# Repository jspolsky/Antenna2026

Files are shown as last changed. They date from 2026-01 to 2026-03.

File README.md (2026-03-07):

Future Turtles 2026 Public LED Display
====

In 2024 we
* upped the number of whips to 24
* got rid of the central antenna
* improved cabling via daisy chaining

For 2026 we
* made the box at the foot of each whip smaller
* hard wired those boxes instead of using external connectors
* used two sources of power so that 16awg wires are adequate
* implemented a bird game

2026 TODO LIST:
===============
- [x] Fix 50 foot cable issues (see below)
- [x] Test game rendering with actual whips
- [x] Replace 600W power supplies with 300W
    - [x] Test temperature inside power packs
    - [x] Install new mounting plates     
- [x] Provide a way to separate left and right halves of whip control harness
    - [x] Modify setup documentation accordingly
- [ ] Implement game button
    - [x] Revise controller PCB to expose more pins (sent to JLCPCB)
    - [x] Rebuild controllers
    - [x] Cable to game button
    - [ ] Game button mounting hardware 
- [x] Finalize game code and flash it onto every MCU
- [ ] Set up a nice spare parts box

50-FOOT CABLE FIX
=================

Yes, the cable length is absolutely the problem. Here's what's happening and how to fix it.

## Why It Breaks with a Long Cable

A 50' cable introduces two nasty problems:

**1. It becomes an antenna.** The long wire efficiently picks up EMI from nearby mains wiring, motors, lighting, etc. This induced noise gets injected directly onto your input pin, causing phantom button presses or preventing real ones from registering cleanly.

**2. Capacitance loads the pullup.** Typical unshielded cable has ~30pF/foot of capacitance. At 50 feet that's ~1,500pF. The Teensy 4.1's internal pullup is a weak ~22kΩ–47kΩ. That RC combination means the pin rises very slowly when the button is released — well outside the clean logic thresholds the chip expects, causing unreliable reads.

---

## Fixes (use in combination)

**1. Add an external pullup resistor (most important)**

Replace the weak internal pullup with a strong external one. Solder a resistor directly from the signal pin to 3.3V *on the Teensy end* of the cable.

| Cable length | Recommended value |
|---|---|
| Up to ~10ft | 10kΩ (internal pullup is fine) |
| ~50ft | **1kΩ – 4.7kΩ** |

In your code, switch from `INPUT_PULLUP` to plain `INPUT` since you're now providing your own pullup.

**2. Add a bypass capacitor**

Place a **100nF ceramic capacitor** from the signal line to GND, right at the Teensy's pin header. This forms a low-pass RC filter with the series resistance of the cable, killing high-frequency noise before it reaches the pin.

```
3.3V
 |
[1kΩ–4.7kΩ]  ← external pullup
 |
 +----[Teensy Pin]
 |
[100nF]       ← bypass cap to GND
 |
GND
```

**3. Use shielded cable**

A shielded cable (e.g., mic cable, alarm wire, or screened 2-conductor) dramatically reduces the antenna effect. Connect the shield to GND at **one end only** (the Teensy end) to avoid ground loops.

**4. Improve software debouncing**

With a long cable you'll want a more generous debounce window even after the hardware fixes. A 20–50ms debounce is reasonable. If you're not already using a library, the [Bounce2](https://github.com/thomasfredericks/Bounce2) library works great on Teensy:

```cpp
#include <Bounce2.h>

Bounce button = Bounce();

void setup() {
  pinMode(BUTTON_PIN, INPUT);       // external pullup, so just INPUT
  button.attach(BUTTON_PIN);
  button.interval(25);              // 25ms debounce
}

void loop() {
  button.update();
  if (button.fell()) {              // button pressed (HIGH → LOW)
    // do the thing
  }
}
```

---

## Quick Summary

The combination of a **1–4.7kΩ external pullup** + **100nF cap to GND at the Teensy pin** will almost certainly solve this. Shielded cable and software debouncing are good additions if you're still seeing noise after that.

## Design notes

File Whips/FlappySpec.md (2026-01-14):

# Flappy Bird - Gameplay Specification

## Display Overview

The game runs on a 24×110 LED array:
- **24 columns** (whips, numbered 0-23 from left to right)
- **110 rows** (LEDs per whip, 0 at bottom, 109 at top)
- Physical size: ~60 feet wide × 6 feet tall
- Viewed from a distance, this creates a wide, short display perfect for side-scrolling gameplay

## Anti-Aliasing / Virtual Resolution

The display is highly responsive to anti-aliasing, so the game uses a **virtual resolution** of **96×440** (4× in each dimension). All game logic runs in this higher resolution space, then downsamples to the physical 24×110 display.

### How It Works
- **Virtual grid**: 96 columns × 440 rows
- **Physical grid**: 24 columns × 110 rows
- **Mapping**: Each physical pixel represents a 4×4 block of virtual pixels
- **Rendering**: The color of each physical LED is the average of its 16 corresponding virtual pixels

### Benefits
- **Smooth motion**: Objects can move in 1/4-pixel increments, eliminating jerky movement
- **Smooth edges**: Pipe edges and the bird appear less blocky
- **Better physics**: Gravity and velocity calculations are more precise
- **Subpixel positioning**: The bird's vertical position feels continuous, not stepped

### Example
A pipe edge at virtual column 40 maps to physical column 10. As it moves left:
- Virtual 40 → Physical pixel 10 is 100% pipe color
- Virtual 39 → Physical pixel 9 is 75% pipe, 25% background (partial coverage)
- Virtual 38 → Physical pixel 9 is 50% pipe, 50% background
- ...and so on, creating smooth motion

## Command Architecture

The serial link between DOM and SUB controllers is bandwidth-constrained. Rather than sending full bitmaps (~8KB per frame), we send compact game state commands.

### cmdFlappyState Structure (~20 bytes)

```cpp
struct cmdFlappyState : cmdUnknown {
    uint8_t gameState;   // 0=ready, 1=playing, 2=gameover
    uint16_t birdY;      // 0-439 virtual Y position
    uint16_t score;
    // 3 pipes maximum
    int16_t pipe1X;      // virtual X (-32 to 96, negative = off-screen left)
    uint16_t pipe1GapY;  // gap center in virtual Y
    int16_t pipe2X;
    uint16_t pipe2GapY;
    int16_t pipe3X;
    uint16_t pipe3GapY;
};
```

### Communication Flow
1. DOM broadcasts `cmdFlappyState` to all SUBs (whip=255) each frame
2. Each SUB receives the same game state
3. Each SUB renders only its own column based on the state
4. All 24 whips stay perfectly synchronized

### Benefits
- **Minimal bandwidth**: ~20 bytes per frame vs ~8KB for full bitmap
- **Synchronized display**: All whips render from identical state
- **Distributed rendering**: Anti-aliasing math spread across 24 processors

## DOM vs SUB Responsibilities

### DOM Controller (Game Master)
- Runs the game loop at 30 FPS
- Handles button input (flap detection)
- Updates bird physics (position, velocity, gravity)
- Manages pipe spawning and movement
- Performs collision detection
- Tracks score
- Broadcasts game state to all SUBs

### SUB Controllers (Display Workers)
- Receive game state via serial
- Determine which virtual columns they represent (whip# × 4 to whip# × 4 + 3)
- Render their 110 LEDs based on game state
- Apply anti-aliasing when objects partially overlap their columns
- No game logic - purely display

## Shared Rendering Library

To ensure the Python visualizer matches the actual LED output exactly, the rendering code is written once in C++ and shared.

### Architecture
```
┌─────────────────────────────────────┐
│     FlappyRender.cpp/.dylib         │
│  renderFlappyState() → RGB buffer   │
└─────────────────────────────────────┘
         ▲                    ▲
         │                    │
    ┌────┴────┐          ┌────┴────┐
    │ SUB MCU │          │ Python  │
    │(direct) │          │(ctypes) │
    └─────────┘          └─────────┘
```

### C++ Interface
```cpp
extern "C" {
    void renderFlappyState(
        uint8_t gameState,
        uint16_t birdY,
        int16_t pipe1X, uint16_t pipe1GapY,
        int16_t pipe2X, uint16_t pipe2GapY,
        int16_t pipe3X, uint16_t pipe3GapY,
        uint8_t* rgbBuffer  // out: 24*110*3 bytes
    );
}
```

### Python Usage
```python
import ctypes
lib = ctypes.CDLL("path/to/libFlappyRender.dylib")
buffer = (ctypes.c_uint8 * (24 * 110 * 3))()
lib.renderFlappyState(state, birdY, p1x, p1gy, p2x, p2gy, p3x, p3gy, buffer)
# buffer now contains RGB data for all 24×110 LEDs
```

### Benefits
- Single source of truth for rendering
- Visualizer output matches hardware exactly
- Changes only need to be made in one place

## Game Elements

All dimensions are in **virtual coordinates** (96×440 grid). Physical display is 24×110.

### The Bird
- **Size**: 12 virtual pixels tall × 4 virtual pixels wide (renders as ~3 LEDs × 1 whip)
- **Position**: Fixed at virtual column 16 (physical column 4)
- **Color**: Bright yellow (RGB: 255, 255, 0)
- **Movement**: Vertical only, controlled by gravity and player input

### Pipes (Obstacles)
- **Structure**: Each pipe is a pair of vertical obstacles with a gap between them
  - Top pipe: Extends down from virtual row 439
  - Bottom pipe: Extends up from the ground
  - Gap: Opening between the pipes where the bird can fly through
- **Gap size**: 80-100 virtual pixels tall (~20-25 physical LEDs, adjustable for difficulty)
- **Width**: 8 virtual pixels wide (~2 physical whips for visibility)
- **Color**: Green (RGB: 0, 255, 0)
- **Movement**: Scroll from right (virtual column 95) to left (virtual column -8)
- **Spacing**: New pipe spawns when previous pipe reaches ~virtual column 60

### Background
- **Color**: Black (LEDs off) - the night sky

### Ground
- **Size**: Bottom 12 virtual pixels (~3 physical LEDs) of every column
- **Color**: Brown or dark orange (RGB: 139, 69, 19)
- **Purpose**: Visual reference and collision boundary (bird dies if it hits the ground)

## Game Mechanics

All physics values are in **virtual coordinates**.

### Physics

**Gravity**
- The bird constantly falls at an accelerating rate
- Fall speed increases over time (simulating acceleration)
- Maximum fall speed capped to prevent instant death

**Flap (Button Press)**
- Each button press gives the bird an upward velocity boost
- The boost is instant - bird immediately starts moving up
- Upward velocity decays quickly, then gravity takes over
- Multiple rapid presses can keep the bird climbing

**Suggested values (tunable, in virtual pixels):**
- Gravity: ~2.0 virtual pixels per frame²
- Flap boost: ~32 virtual pixels upward velocity
- Max fall speed: ~24 virtual pixels per frame
- Frame rate: ~30 FPS (33ms per frame)

### Pipe Generation

- Pipes spawn off-screen to the right (virtual column 96+)
- Gap position is randomized but constrained:
  - Gap center must be between virtual row 100 and virtual row 340
  - This prevents impossible gaps too close to top/bottom/ground
- Pipes move left at a constant speed (~1 virtual column per frame = smooth motion)
- Maximum 3 pipes on screen at once
- When a pipe scrolls completely off the left edge (virtual X < -8), it's removed

### Collision Detection

The bird collides (game over) when:
1. Bird touches any part of a pipe (top or bottom section)
2. Bird touches the ground (virtual Y < 12)
3. Bird goes above the ceiling (virtual Y > 439)

**Hit box**: The bird's 12 virtual pixel height is the collision zone. DOM performs all collision checks.

### Scoring

- **+1 point** each time a pipe's right edge passes the bird's column
- Score tracked by DOM controller
- **No high score feature** - intentional design to encourage player turnover

## Game States

The game integrates with the existing `LedShow::Mode` system. A new mode `flappy` is added alongside `gif`, `solid`, and `selfID`.

### 1. Attract Mode = GIF Mode (Existing)
- The normal animated GIF display serves as the attract mode
- Beautiful visuals draw people to the installation
- When a passerby discovers the button and presses it, the game begins
- **Transition**: Button press switches `LedShow::Mode` from `gif` to `flappy`

### 2. Ready State (Flappy Mode - Initial)
- Bird appears at starting position (virtual column 16, virtual Y ~220)
- Bird gently hovers/bobs to show it's alive and ready
- Ground is visible at bottom
- No pipes on screen yet
- Player has a moment to understand they're about to play
- **Transition**: Next button press starts the game

### 3. Playing State (Flappy Mode - Active)
- Full game physics active
- Pipes spawning and scrolling from right to left
- Score incrementing as pipes are passed
- Collision detection active
- **Transition**: Collision ends the game

### 4. Game Over State (Flappy Mode - End)
- Bird flashes or changes color (red) briefly
- All movement stops
- **Score display**: Large numerals scroll smoothly from right to left across all whips
  - Scrolling with anti-aliasing makes numbers readable despite 30" whip spacing
  - Numbers are tall (most of the whip height) for visibility
- After score finishes scrolling, automatically return to GIF mode (attract)
- **Transition**: Scroll completion returns to `gif` mode

## Visual Feedback

### Successful Pipe Pass
- Brief flash or color pulse when scoring
- Subtle enough not to distract, but rewarding

### Collision
- Screen flash (all whips briefly red or white)
- Bird changes color to red
- Pipes freeze in place momentarily

### Score Display (Game Over)
- Large numerals scroll smoothly right-to-left across all 24 whips
- Anti-aliased scrolling creates readable motion despite physical spacing
- Numbers fill most of the whip height for visibility from a distance

## Difficulty Progression (Optional)

As score increases:
- Pipe scroll speed increases slightly
- Gap size decreases slightly
- Pipe spacing decreases slightly

Starting easy, getting progressively harder keeps players engaged.

## Control Summary

| Input | Action |
|---|---|
| Button press | Flap (give bird upward velocity) |
| No input | Bird falls (gravity) |

That's it - one button, simple and intuitive!

## Technical Considerations (for implementation)

- Game loop runs on DOM controller at 30 FPS
- Each frame: update physics, check collisions, broadcast `cmdFlappyState`
- All 24 whips receive identical game state simultaneously
- Each SUB renders its column using shared `FlappyRender` library
- Shared library (.dylib) ensures Python visualizer matches hardware exactly
- Visualizer enables full development/testing without physical hardware
- Anti-aliasing calculations distributed across 24 SUB processors

## Future Enhancements (Beyond MVP)

- Sound effects via buzzer
- Two-player mode (birds at different columns)
- Different bird colors/characters
- Day/night themes
- Moving obstacles (birds, clouds)
- Power-ups (slow motion, invincibility)

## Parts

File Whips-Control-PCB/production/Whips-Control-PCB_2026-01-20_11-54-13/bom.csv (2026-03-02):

Designator | Footprint | Quantity | Value | LCSC Part #
J1, J4 | TerminalBlock_Phoenix_MKDS-1,5-4_1x04_P5.00mm_Horizontal | 2 | Conn_01x04_Pin
MAX485 | Max485-Module | 1 | MAX485E
TEENSY 4.1 | Teensy41_Minimal | 1 | Teensy4.1_Minimal
U3 | Vishay_MOLD-3Pin | 1 | TSOP341xx

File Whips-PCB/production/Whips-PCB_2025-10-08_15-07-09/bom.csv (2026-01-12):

Designator | Footprint | Quantity | Value | LCSC Part #
C1 | 0402 | 1 | 0.1uF | C1525
C2 | 0402 | 1 | 10uF | C15525
D1 | 0603 | 1 | LED | C2286
D2 | 0603 | 1 | LED | C2290
J2 | Dorabo_DB103-5.0-5P-GN-S | 1 | Conn_01x05_Socket | C395854
R1, R2 | 0603 | 2 | 20K | C4184
R3, R4 | 0603 | 2 | 10K | C25804
R5 | 0402 | 1 | 120 | C25079
R6, R9 | 0402 | 2 | 470 | C25117
SW1 | DongGuan_DSWB06LHGET_6_PIN_DIP | 1 | DSWB06LHGET | C99416
U2 | SOIC-8_3.9x4.9mm_P1.27mm | 1 | MAX485ESA+T | C19738
U3 | SOIC-14_3.9x8.7mm_P1.27mm | 1 | SN74AHCT125DR | C155176
U4 | Converter_DCDC_TRACO_TSR-1_THT | 1 | TSR_1-2450 | DNP
U6 | Teensy41_Minimal | 1 | Teensy4.1_Minimal | DNP

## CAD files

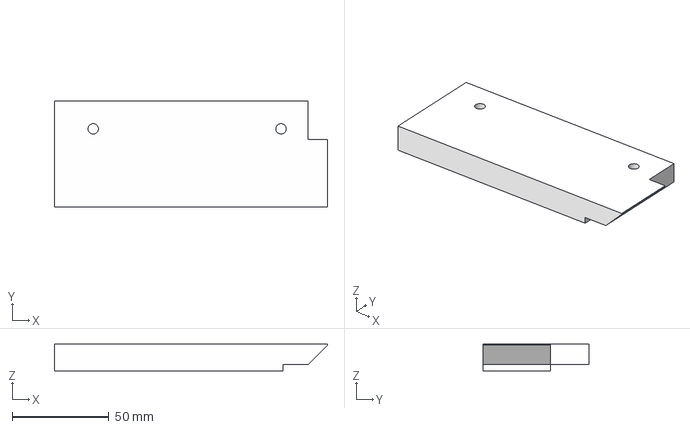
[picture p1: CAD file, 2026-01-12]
Power-Supply-Box/PowerSupplyBoxMound.3mf
141.0 x 55.0 x 13.8 mm

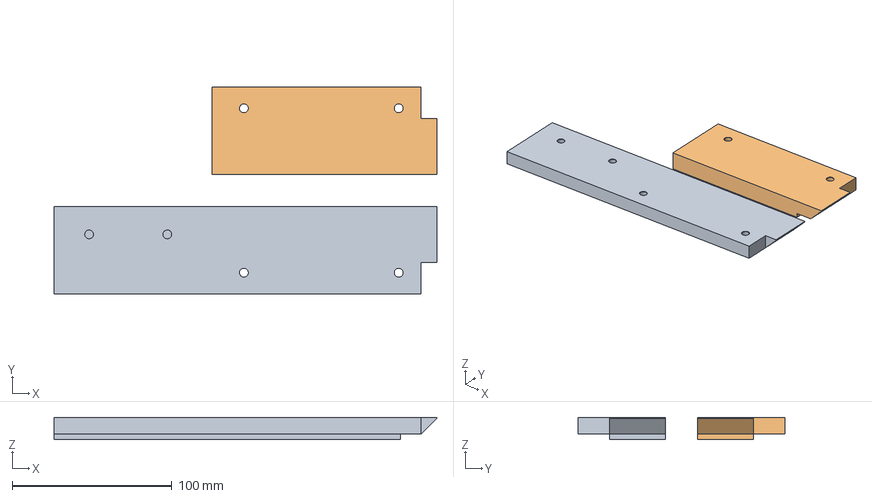
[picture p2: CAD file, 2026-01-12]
Power-Supply-Box/PowerSupplyBoxMountBoth.3mf
240.0 x 130.0 x 13.8 mm

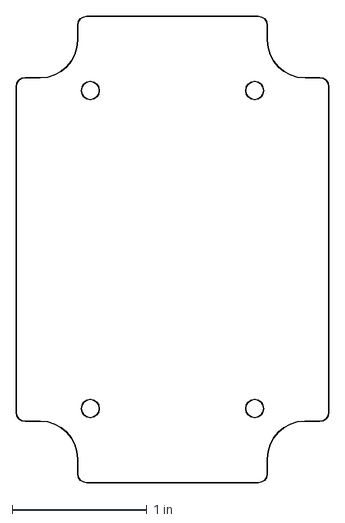
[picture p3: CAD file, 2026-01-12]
SK-12-Box/Drawing2.dxf
2.32 x 3.46 in

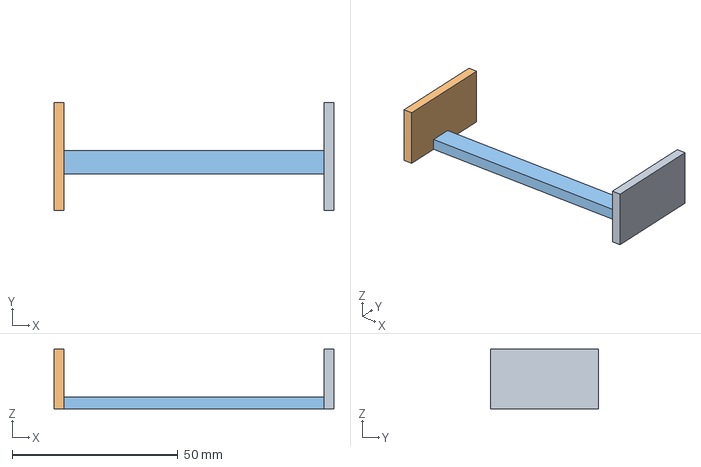
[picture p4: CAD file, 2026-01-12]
SK-12-Box/lidbrace.3mf
84.5 x 32.5 x 18.0 mm

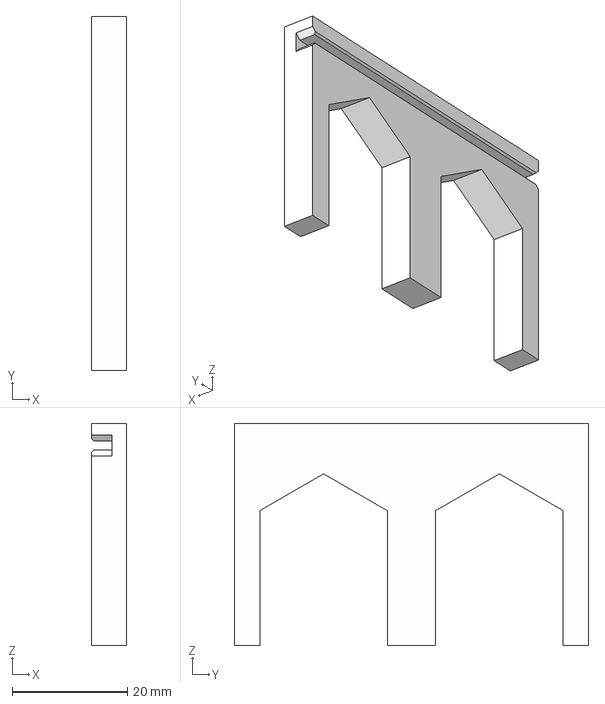
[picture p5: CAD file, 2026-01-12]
SK-12-Box/edge.3mf
6.00 x 61.4 x 38.5 mm

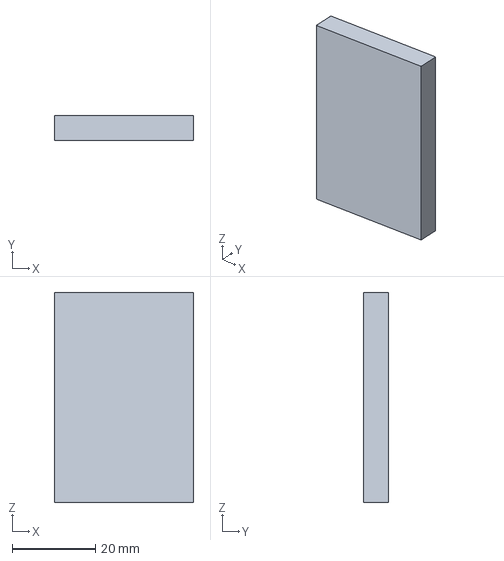
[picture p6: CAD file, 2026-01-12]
SK-12-Box/revised-clip.stp
33.5 x 6.00 x 50.5 mm

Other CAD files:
SK-12-Box/SK-12_1_Sheet1.dwg
Power-Supply-Box/PowerSupplyBoxMount-Right.3mf
SK-12-Box/SK-12C.dwg
SK-12-Box/SK-12B.dwg
SK-12-Box/SK-12_2_Sheet2.dwg
Doc/Illustration for Installation Manual.3dm
SK-12-Box/edge.3dm
SK-12-Box/lidbrace.3dm
SK-12-Box/revised-clip.3dm
SK-12-Box/revised-clip.3mf

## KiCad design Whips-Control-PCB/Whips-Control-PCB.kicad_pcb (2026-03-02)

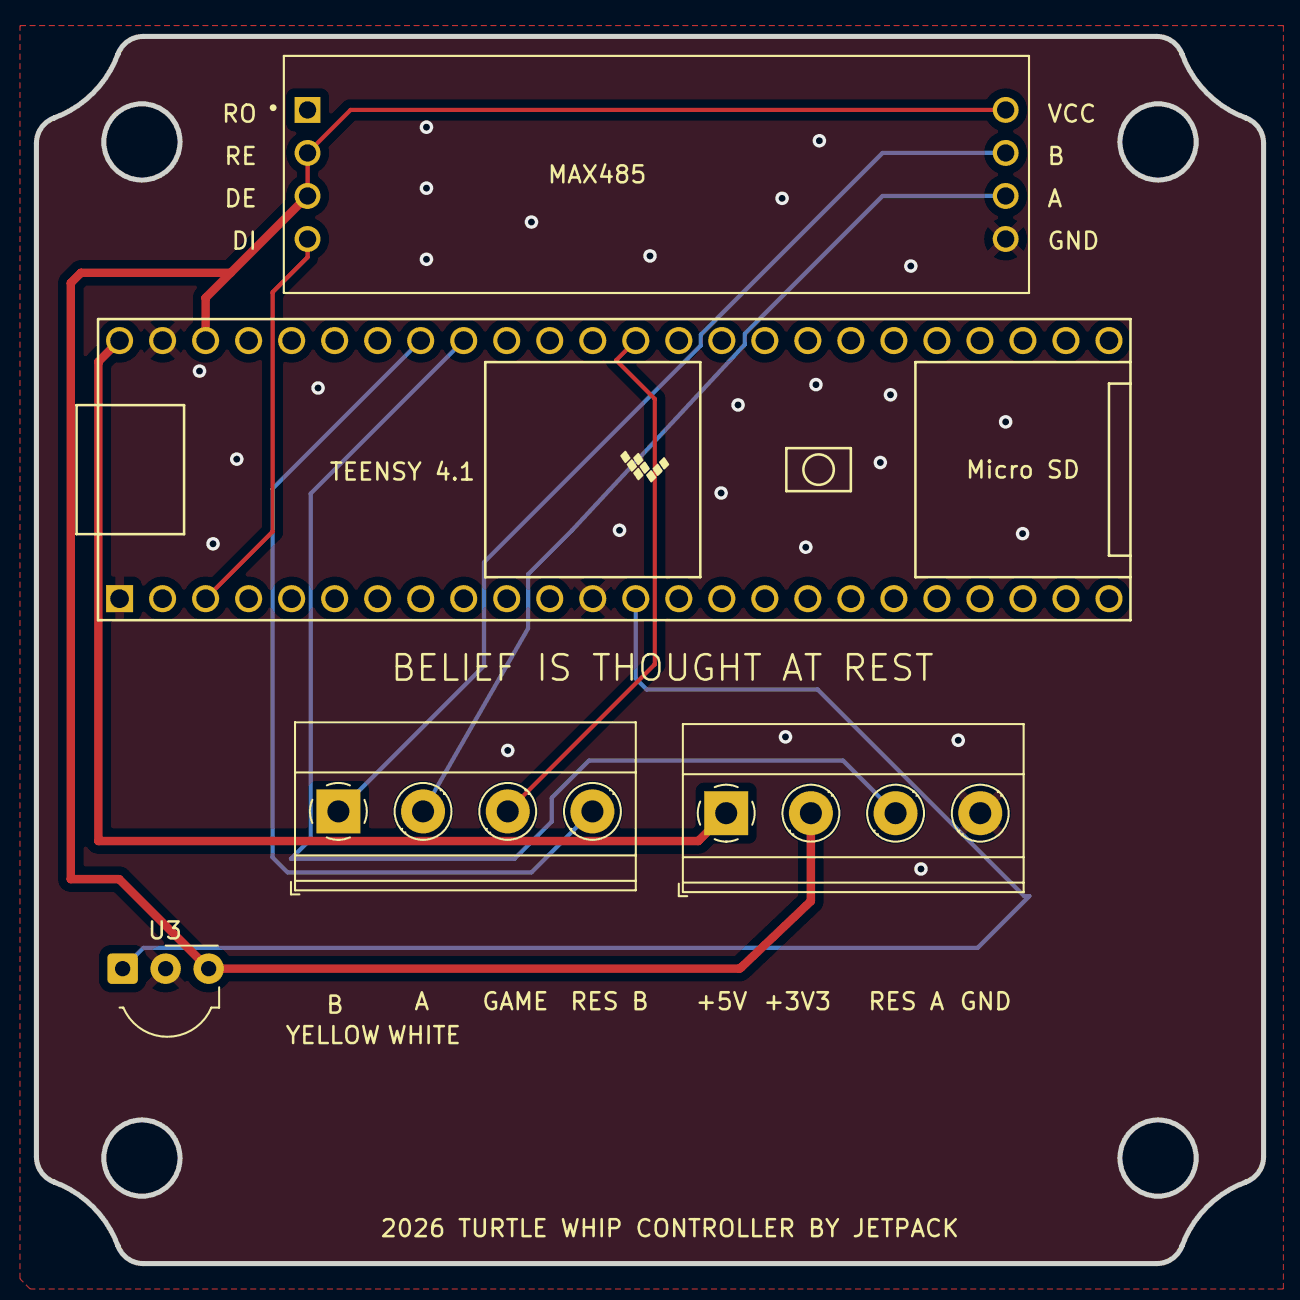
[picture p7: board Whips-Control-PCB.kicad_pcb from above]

Board: 2 copper layers, 72.5 x 72.5 mm, 5 parts (0 on the bottom side), 10 nets.

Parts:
J1, J4: Conn_01x04_Pin; TerminalBlock_Phoenix_MKDS-1,5-4_1x04_P5.00mm_Horizontal
MAX485: MAX485E; Max485-Module
TEENSY 4.1: Teensy4.1_Minimal; Teensy41_Minimal
U3: TSOP341xx; Vishay_MOLD-3Pin

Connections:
+3.3V: J1.2, MAX485.2 (~RE), MAX485.3 (DE), MAX485.8 (VCC), TEENSY 4.1.46 (3V3), U3.3 (Vs)
+5V: J1.1, TEENSY 4.1.48 (VIN)
/A: J4.2, MAX485.6 (A)
/B: J4.1, MAX485.7 (B)
/DI: MAX485.4 (DI), TEENSY 4.1.3 (1_TX1_CTX2_MISO1)
/GAME: J4.3, TEENSY 4.1.36 (14_A0_TX3_SPDIF_OUT)
/IR: TEENSY 4.1.13 (11_MOSI_CTX1), U3.1 (OUT)
/RESERVEDA: J1.3, TEENSY 4.1.40 (18_A4_SDA)
/RESERVEDB: J4.4, TEENSY 4.1.41 (19_A5_SCL)
GND: J1.4, MAX485.5 (GND), TEENSY 4.1.1 (GND), TEENSY 4.1.12 (10_CS_MQSR), TEENSY 4.1.47 (GND), U3.2 (GND)

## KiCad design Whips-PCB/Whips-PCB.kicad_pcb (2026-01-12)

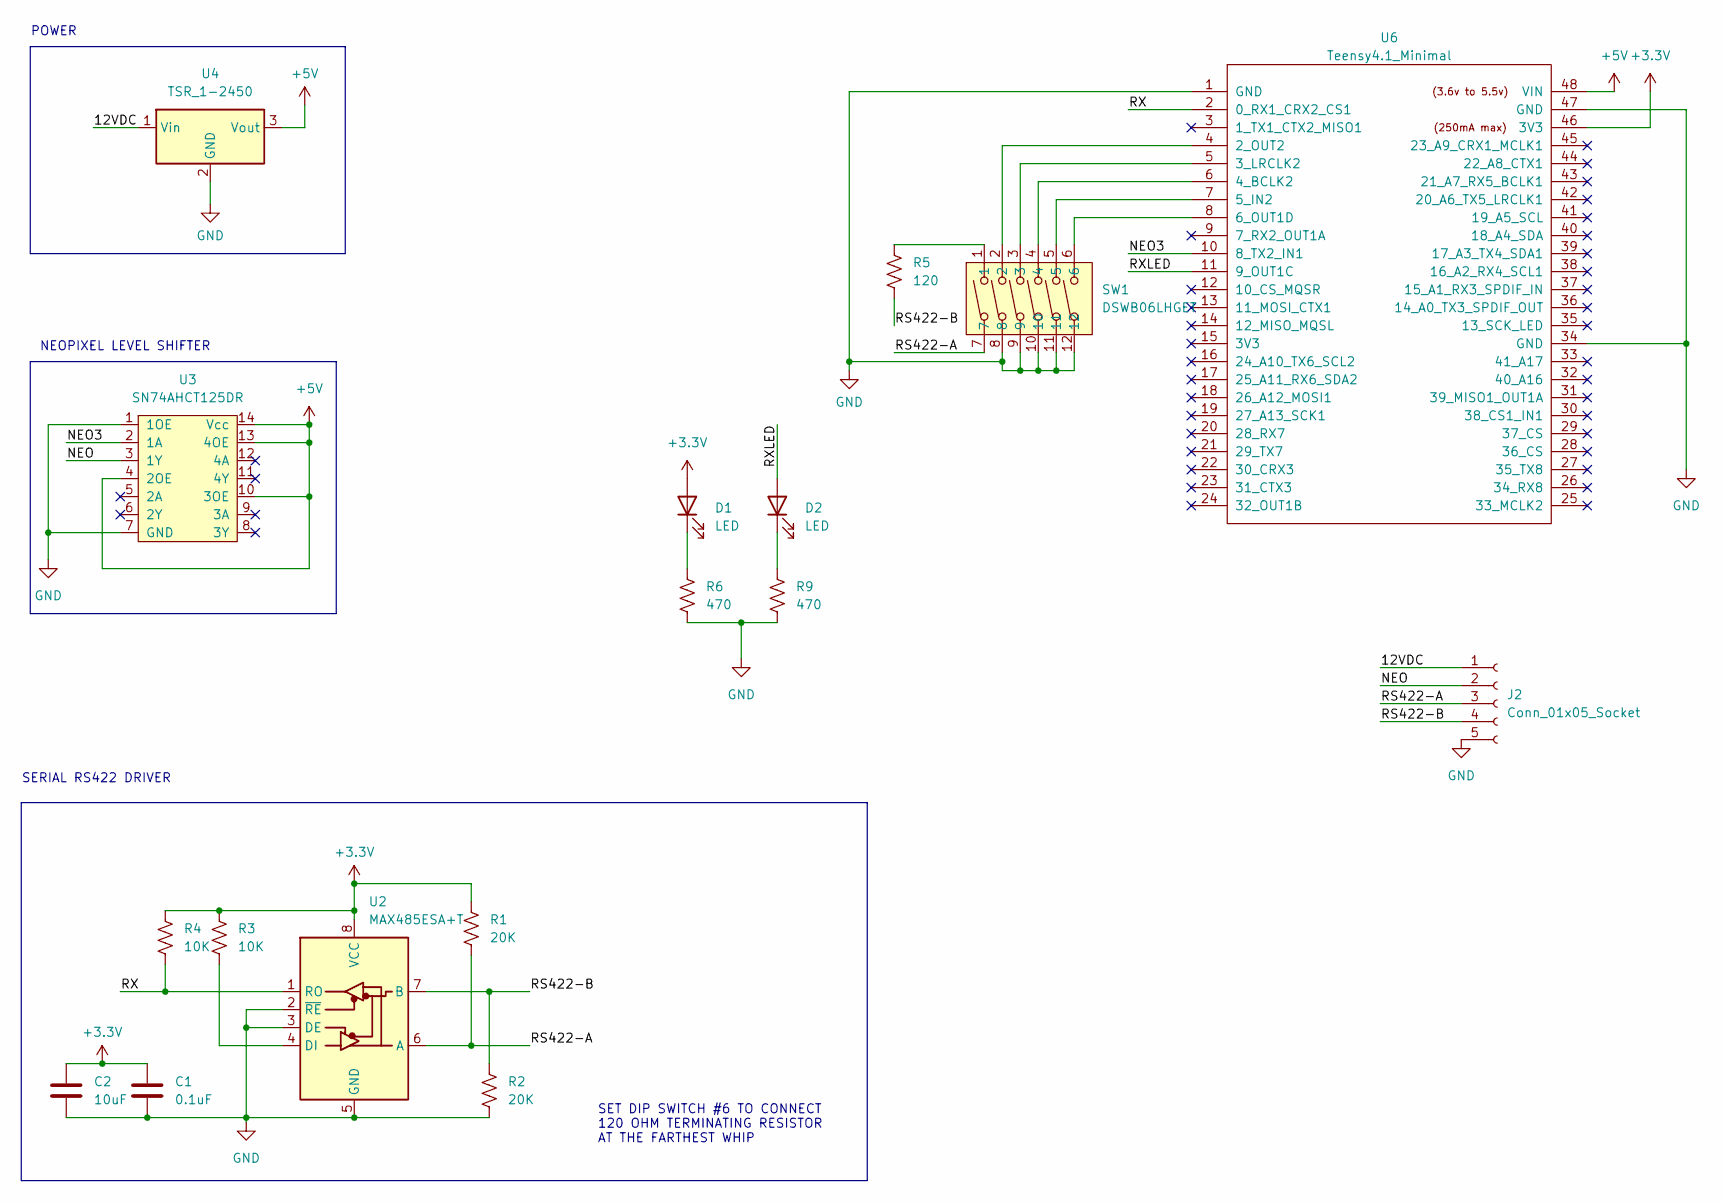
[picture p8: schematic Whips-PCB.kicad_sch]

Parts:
C1: 0.1uF; C_0402_1005Metric; LCSC C1525
C2: 10uF; C_0402_1005Metric; LCSC C15525
D1: LED; LED_0603_1608Metric; LCSC C2286
D2: LED; LED_0603_1608Metric; LCSC C2290
J2: Conn_01x05_Socket; Dorabo_DB103-5.0-5P-GN-S; LCSC C395854
R1, R2: 20K; R_0603_1608Metric; LCSC C4184
R3, R4: 10K; R_0603_1608Metric; LCSC C25804
R5: 120; R_0402_1005Metric; LCSC C25079
R6, R9: 470; R_0402_1005Metric; LCSC C25117
SW1: DSWB06LHGET; DongGuan_DSWB06LHGET_6_PIN_DIP; LCSC Part C99416
U2: MAX485ESA+T; SOIC-8_3.9x4.9mm_P1.27mm; LCSC C19738
U3: SN74AHCT125DR; SOIC-14_3.9x8.7mm_P1.27mm; LCSC C155176
U4: TSR_1-2450; Converter_DCDC_TRACO_TSR-1_THT; LCSC DNP
U6: Teensy4.1_Minimal; Teensy41_Minimal; LCSC DNP

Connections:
+3.3V: C1.1, C2.1, D1.2 (A), R1.1, R3.1, R4.1, U2.8 (VCC), U6.46 (3V3)
+5V: U3.4 (2OE), U3.10 (3OE), U3.13 (4OE), U3.14 (Vcc), U4.3 (Vout), U6.48 (VIN)
/12VDC: J2.1, U4.1 (Vin)
/NEO: J2.2, U3.3 (1Y)
/NEO3: U3.2 (1A), U6.10 (8_TX2_IN1)
/RS422-A: J2.3, R1.2, SW1.7, U2.6 (A)
/RS422-B: J2.4, R2.2, R5.2, U2.7 (B)
/RX: R4.2, U2.1 (RO), U6.2 (0_RX1_CRX2_CS1)
/RXLED: D2.2 (A), U6.11 (9_OUT1C)
GND: C1.2, C2.2, J2.5, R2.1, R6.2, R9.2, SW1.8, SW1.9, SW1.10, SW1.11, SW1.12, U2.2 (~RE), U2.3 (DE), U2.5 (GND), U3.1 (1OE), U3.7 (GND), U4.2 (GND), U6.1 (GND), U6.34 (GND), U6.47 (GND)
unnamed: D1.1 (K), R6.1
unnamed: D2.1 (K), R9.1
unnamed: R5.1, SW1.1
unnamed: R3.2, U2.4 (DI)
unnamed: SW1.2, U6.4 (2_OUT2)
unnamed: SW1.3, U6.5 (3_LRCLK2)
unnamed: SW1.4, U6.6 (4_BCLK2)
unnamed: SW1.5, U6.7 (5_IN2)
unnamed: SW1.6, U6.8 (6_OUT1D)

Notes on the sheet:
POWER
SERIAL RS422 DRIVER
NEOPIXEL LEVEL SHIFTER
SET DIP SWITCH #6 TO CONNECT 120 OHM TERMINATING RESISTOR AT THE FARTHEST WHIP

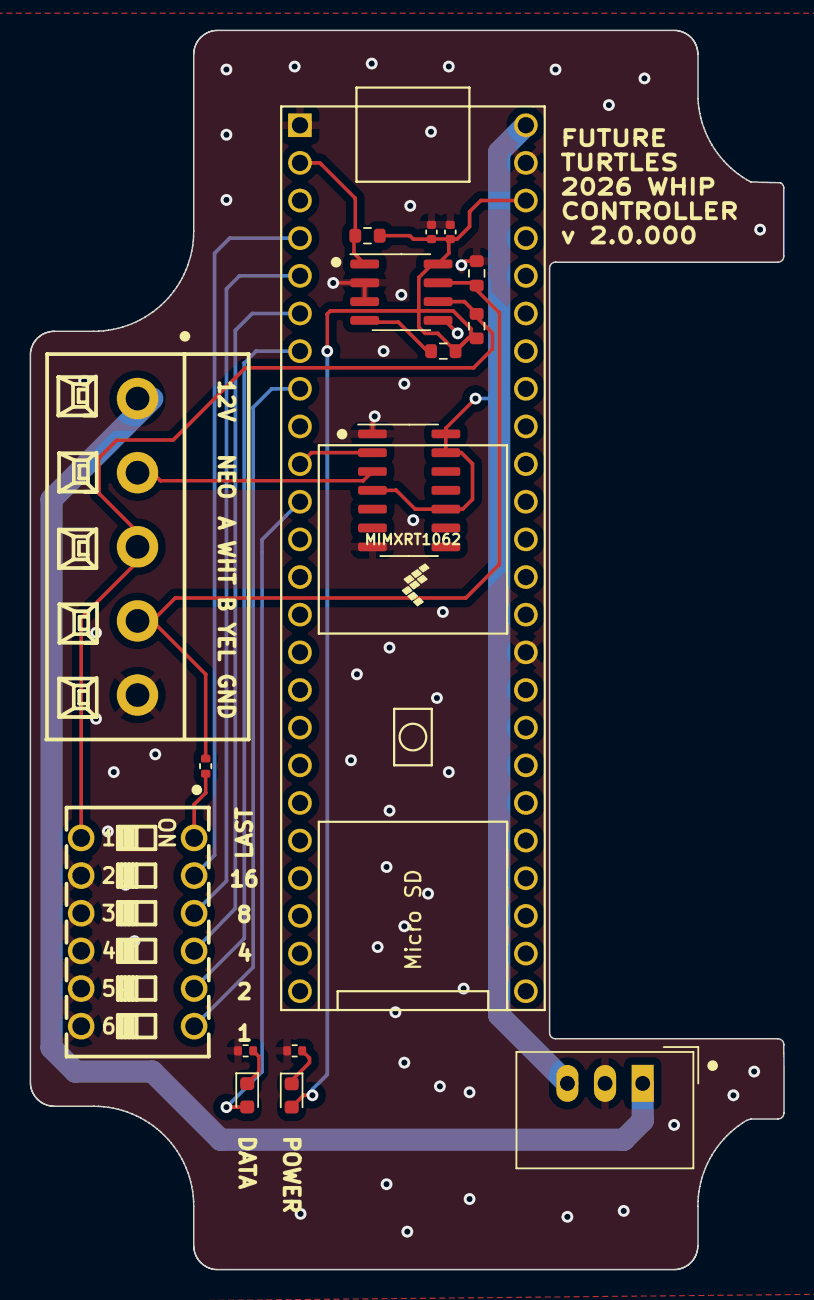
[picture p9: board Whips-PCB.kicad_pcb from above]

Board: 2 copper layers, 50.8 x 83.6 mm, 17 parts (0 on the bottom side), 19 nets.

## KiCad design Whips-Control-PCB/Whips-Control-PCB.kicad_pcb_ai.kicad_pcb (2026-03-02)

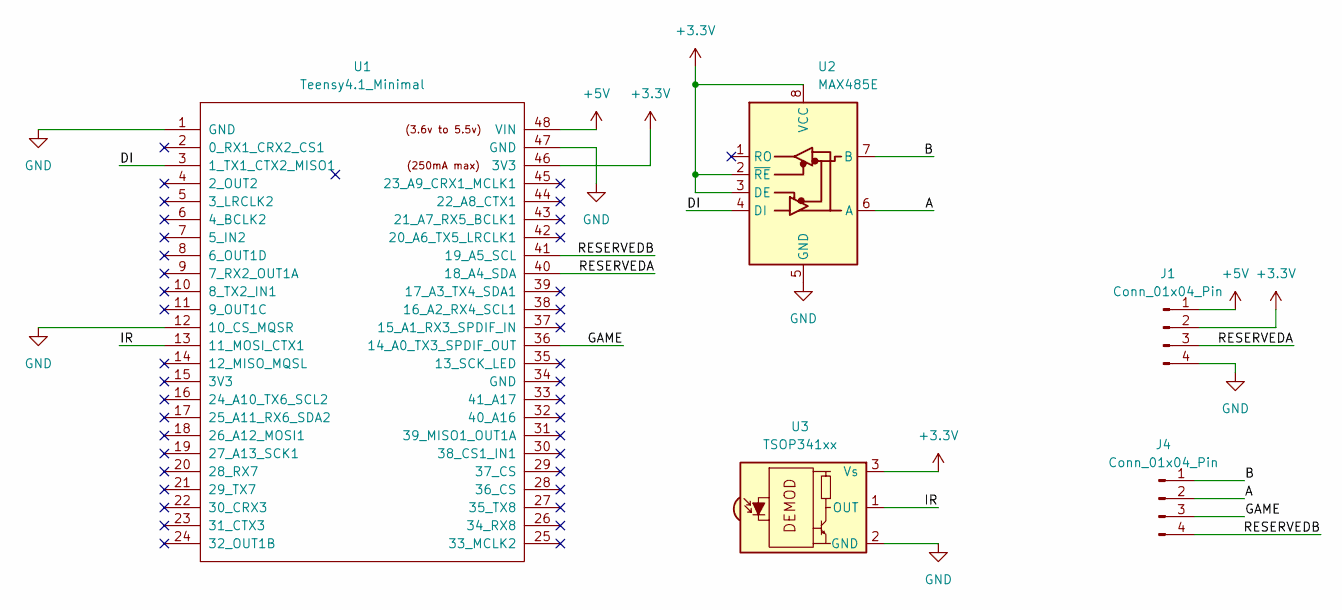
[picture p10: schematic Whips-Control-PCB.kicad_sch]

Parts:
J1, J4: Conn_01x04_Pin; TerminalBlock_Phoenix_MKDS-1,5-4_1x04_P5.00mm_Horizontal
U1: Teensy4.1_Minimal; Teensy41_Minimal
U2: MAX485E; Max485-Module
U3: TSOP341xx; Vishay_MOLD-3Pin

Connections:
+3.3V: J1.2, U1.46 (3V3), U2.2 (~RE), U2.3 (DE), U2.8 (VCC), U3.3 (Vs)
+5V: J1.1, U1.48 (VIN)
/A: J4.2, U2.6 (A)
/B: J4.1, U2.7 (B)
/DI: U1.3 (1_TX1_CTX2_MISO1), U2.4 (DI)
/GAME: J4.3, U1.36 (14_A0_TX3_SPDIF_OUT)
/IR: U1.13 (11_MOSI_CTX1), U3.1 (OUT)
/RESERVEDA: J1.3, U1.40 (18_A4_SDA)
/RESERVEDB: J4.4, U1.41 (19_A5_SCL)
GND: J1.4, U1.1 (GND), U1.12 (10_CS_MQSR), U1.47 (GND), U2.5 (GND), U3.2 (GND)

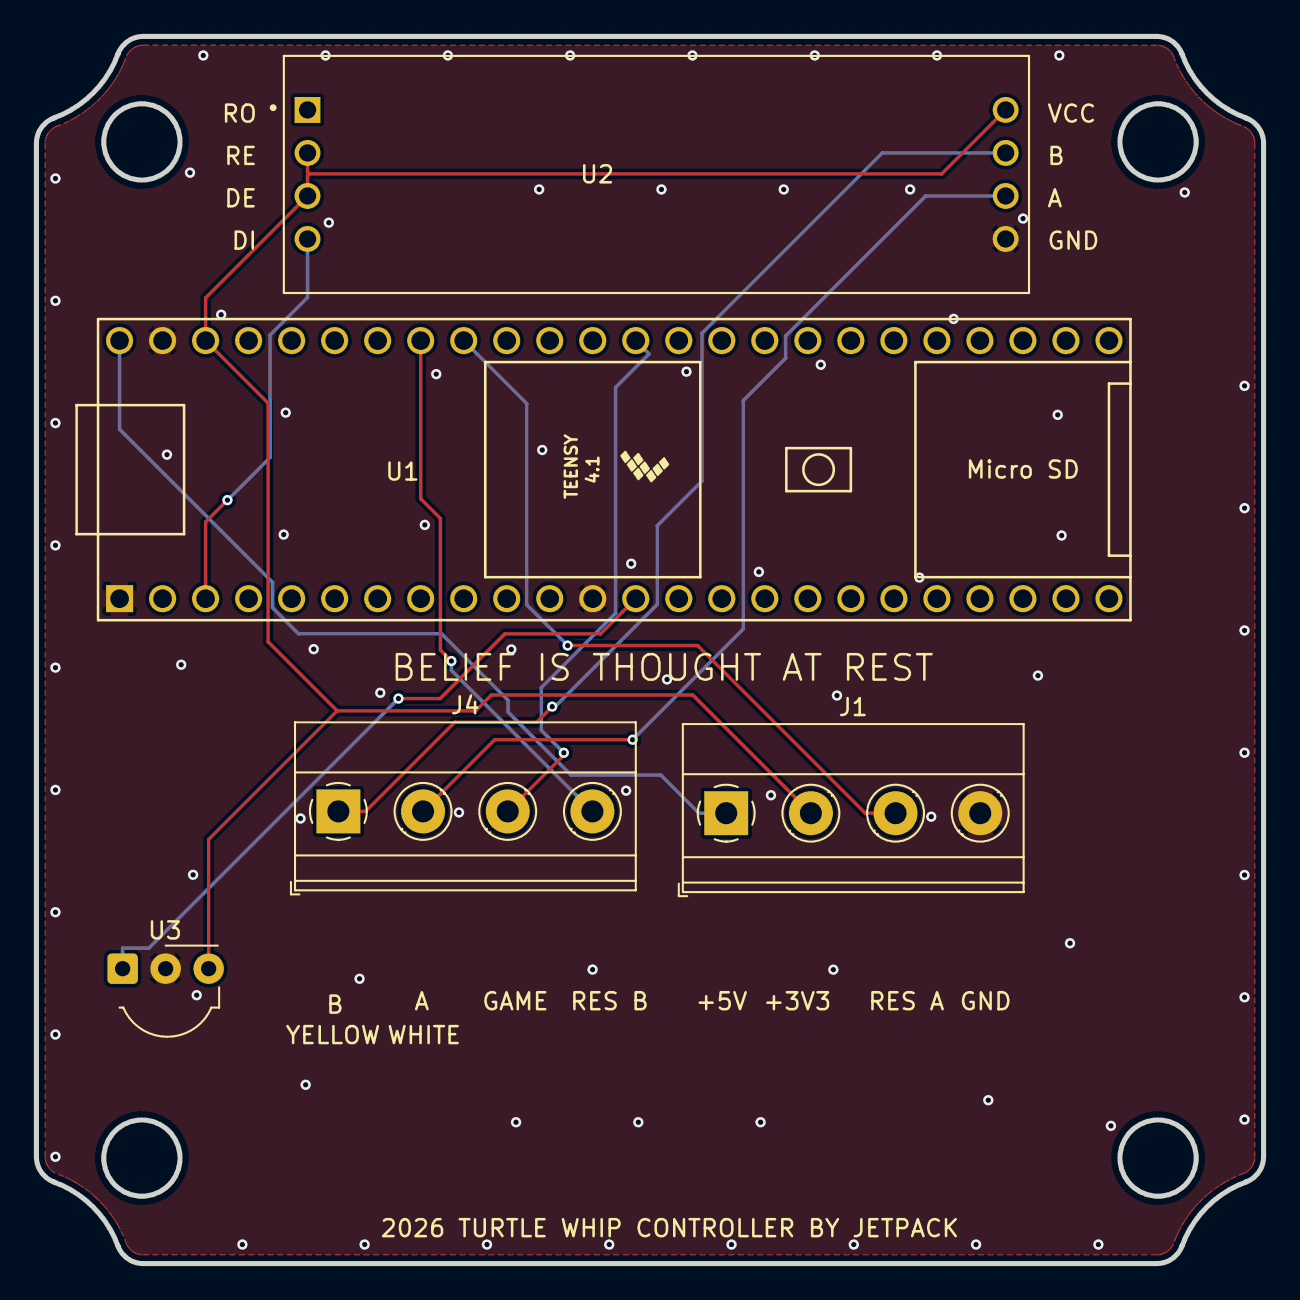
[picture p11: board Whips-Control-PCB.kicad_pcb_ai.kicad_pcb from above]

Board: 2 copper layers, 72.5 x 72.5 mm, 5 parts (0 on the bottom side), 10 nets.

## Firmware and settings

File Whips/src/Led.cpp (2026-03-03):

#include <Arduino.h>
#include <PacketSerial.h>
#include <CRC16.h>
#include <CRC.h>

#include "pins.h"
#include "Util.h"
#include "Led.h"
#include "Commands.h"
#include "DipSwitch.h"
#include "Gif.h"
#include "FlappyRender.h"

namespace Led
{

    CRGB leds[NUM_LEDS];
    PacketSerial packetSerial;
    uint8_t brightness = 32;
    uint8_t bottomLED = 0;
    uint8_t topLED = NUM_LEDS - 1;
    bool rangeFlashing = false;
    unsigned long lastPacketTime = 0;

    // Overlay boundary LEDs white when range flash is active
    void applyRangeFlash()
    {
        if (rangeFlashing)
        {
            leds[bottomLED] = CRGB::White;
            leds[topLED] = CRGB::White;
        }
    }

    void setup()
    {
        Serial1.begin(2000000);
        packetSerial.setStream(&Serial1);
        packetSerial.setPacketHandler(&onPacketReceived);

        FastLED.addLeds<WS2812SERIAL, pinLEDStrip, BGR>(leds, NUM_LEDS);
        FastLED.setBrightness(brightness);
        FastLED.showColor(CRGB::DarkOrange);

        pinMode(pinLEDRxIndicator, OUTPUT);
    }

    void loop()
    {
        packetSerial.update();

        EVERY_N_MILLIS(200)
        {
            digitalWriteFast(pinLEDRxIndicator, LOW);
        }

        // Idle animation when no packets received for 2 seconds
        if (millis() - lastPacketTime > 2000)
        {
            EVERY_N_MILLIS(20)
            {
                // Sine bounce: 5-pixel orange element, 3-second period
                float t = millis() / 3000.0f * 2.0f * 3.14159f;
                float center = (NUM_LEDS - 1) / 2.0f +
                               ((NUM_LEDS - 1) / 2.0f - 2.0f) * sinf(t);
                int centerLED = (int)(center + 0.5f);

                for (int i = 0; i < NUM_LEDS; i++)
                {
                    if (i >= centerLED - 2 && i <= centerLED + 2)
                        leds[i] = CRGB::DarkOrange;
                    else
                        leds[i] = CRGB::Black;
                }
                FastLED.show();
            }
        }
    }

    void onPacketReceived(const uint8_t *buffer, size_t size)
    {
        if (size < sizeof(cmdUnknown))
        {
            // impossible packet doesn't even have room for checksum and command
            return;
        }

        cmdUnknown *punk = (cmdUnknown *)buffer;

        uint16_t checksum = punk->checksum;
        punk->checksum = 0; // when packet checksum was calculated, these 2 bytes were 0

        if (checksum != calcCRC16(buffer, size))
        {
            // packet garbled
            dbgprintf("garbled packet. Size was %d\n", size);
            return;
        }

        digitalWriteFast(pinLEDRxIndicator, HIGH);

        if (punk->whip != DipSwitch::getWhipNumber() && punk->whip != 255)
        {
            // not a message for us
            return;
        }

        lastPacketTime = millis();

        switch (punk->chCommand)
        {
        case 'c':
        {
            cmdSetWhipColor *pSetWhipColor = (cmdSetWhipColor *)buffer;
            fill_solid(leds, NUM_LEDS, pSetWhipColor->rgb);
            applyRangeFlash();
            FastLED.show();
        }
        break;

        case 'b':
        {

            cmdSetBrightness *pSetBrightness = (cmdSetBrightness *)buffer;
            if (brightness != pSetBrightness->brightness)
            {
                brightness = pSetBrightness->brightness;
                FastLED.setBrightness(128);
                int ixBrightness = map(brightness, 0, 255, 0, NUM_LEDS);
                for (int i = 0; i < ixBrightness; i++)
                {
                    leds[i] = CRGB::White;
                }
                for (int i = ixBrightness; i < NUM_LEDS; i++)
                {
                    leds[i] = CRGB::Black;
                }
                FastLED.show();
                FastLED.delay(200);
                FastLED.setBrightness(pSetBrightness->brightness);
            }
        }
        break;

        case 'g':
        {
            if (DipSwitch::getWhipNumber() <= 23)
            {
                static uint16_t iGifLoaded = 0;

                cmdShowGIFFrame *pShowGIFFrame = (cmdShowGIFFrame *)buffer;

                if (iGifLoaded != pShowGIFFrame->iGifNumber)
                {
                    Gif::LoadGif(iGifLoaded = pShowGIFFrame->iGifNumber);
                    dbgprintf("Loading gif number %d\n", pShowGIFFrame->iGifNumber);
                }
                Gif::GetFrame(pShowGIFFrame->frame, leds);
                applyRangeFlash();
                FastLED.show();
            }
            else
            {
                FastLED.showColor(CRGB::Red);
            }
            break;
        }

        case 'i':
        {
            uint8_t whip = DipSwitch::getWhipNumber();

            for (int i = 0; i < NUM_LEDS; i++)
                leds[i] = CRGB::Black;

            for (int i = 0; i < 5; i++)
            {
                for (int led = i * 20; led < (i + 1) * 20 - 3; led++)
                {
                    if (whip & 0x01)
                        leds[led] = CRGB::White;
                }
                for (int led = (i + 1) * 20 - 3; led < (i + 1) * 20; led++)
                {
                    leds[led] = CRGB::Red;
                }
                whip >>= 1;
            }

            FastLED.show();
            break;
        }

        case 'r':
        {
            cmdSetGameRange *pRange = (cmdSetGameRange *)buffer;
            bottomLED = pRange->bottomLED;
            topLED = pRange->topLED;
            rangeFlashing = (pRange->flashRange > 0);
            break;
        }

        case 'f':
        {
            // Flappy Bird game state - render this whip's column
            cmdFlappyState *pFlappy = (cmdFlappyState *)buffer;
            uint8_t whipNum = DipSwitch::getWhipNumber();

            if (whipNum < FLAPPY_PHYSICAL_WIDTH)
            {
                // Buffer for RGB data (110 LEDs * 3 bytes)
                uint8_t rgbBuffer[FLAPPY_PHYSICAL_HEIGHT * 3];

                // Render just this whip's column
                renderFlappyColumn(
                    whipNum,
                    pFlappy->gameState,
                    pFlappy->birdY,
                    pFlappy->score,
                    pFlappy->pipe1X, pFlappy->pipe1GapY,
                    pFlappy->pipe2X, pFlappy->pipe2GapY,
                    pFlappy->pipe3X, pFlappy->pipe3GapY,
                    pFlappy->scrollX,
                    pFlappy->flashWhip,
                    bottomLED,
                    topLED,
                    rgbBuffer);

                // Copy RGB buffer to FastLED array
                for (int i = 0; i < FLAPPY_PHYSICAL_HEIGHT; i++)
                {
                    leds[i].r = rgbBuffer[i * 3];
                    leds[i].g = rgbBuffer[i * 3 + 1];
                    leds[i].b = rgbBuffer[i * 3 + 2];
                }

                applyRangeFlash();
                FastLED.show();
            }
            break;
        }
        }
    }
}

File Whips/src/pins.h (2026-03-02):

#define pinLEDStrip 8

// Which SD Card are we using?
// BUILTIN_SDCARD - for Teensy 4.1
// 10 - when connected to external SD Card using SPI
//      Currently not using this because it is not fast enough
//      and causes audio to sound crap
#define pinSDCardCS BUILTIN_SDCARD
// #define pinSDCardCS 10

#define pinStatus LED_BUILTIN
#define pinBrightness A0

#define pinDip16 2
#define pinDip8 3
#define pinDip4 4
#define pinDip2 5
#define pinDip1 6

#define pinLEDRxIndicator 9
#define pinGndMeansDom 10
#define pinIR 11

#define pinButton 14
#define pinReservedA 18 /* exposed on controller PCB for future use */
#define pinReservedB 19 /* exposed on controller PCB for future use */

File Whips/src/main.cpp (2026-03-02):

#include <Arduino.h>

#include "pins.h"
#include "Util.h"
#include "Led.h"
#include "LedShow.h"
#include "DipSwitch.h"
#include "SDCard.h"
#include "Gif.h"
#include "IR.h"
#include "Button.h"

static bool domMode;

void setup()
{
  Util::setup();
  pinMode(pinGndMeansDom, INPUT_PULLUP); // this takes a millisecond to pull up the pin; it MUST be before the delay() before you can start reading the pin

  dbgprintf("Starting\n");
  delay(100);

  if (!(SD.begin(pinSDCardCS)))
  {
    dbgprintf("Unable to access sd card\n");
    return;
  }

  domMode = (digitalReadFast(pinGndMeansDom) == LOW);
  dbgprintf("Whip controller in %s mode\n", domMode ? "DOM" : "SUB");

  if (domMode)
  {
    LedShow::setup();
    IR::setup();
    Button::setup();
  }
  else
  {
    DipSwitch::setup();
    Led::setup();
  }
  Gif::setup();
}

void loop()
{
  if (domMode)
  {
    IR::Op op = IR::loop();
    LedShow::loop(op);
    Button::loop();

    EVERY_N_SECONDS(20)
    {
      LedShow::loop(IR::nextImageSuggested);
    }
  }
  else
  {
    DipSwitch::loop();
    Led::loop();
  }
}

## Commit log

2026-01-12 Antenna 2026 initiated; new controller PCB
    [Drawing2.dxf, Illustration for Installation Manual.3dm, PowerSupplyBoxMound.3mf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]
2026-01-13 got a button working...
2026-01-14 fixed some compilation warnings
    [Util.cpp]
2026-01-14 flashing effect on collision
    [Flappy.h, FlappyRender.h, Led.cpp]
2026-01-14 fixed bug indicating collision with ground
2026-03-02 this is a new PCB for the controller, to fit in a smaller box
    [Whips-Control-PCB.kicad_pcb, Whips-Control-PCB.kicad_pcb_ai.kicad_pcb, Whips-Control-PCB.kicad_sch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]
